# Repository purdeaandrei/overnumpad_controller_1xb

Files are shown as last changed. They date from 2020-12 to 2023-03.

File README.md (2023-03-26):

# OverNumpad Controller

This is a replacement keyboard controller, for 4th generation IBM/Lexmark
Model M keyboards, and Unicomp keyboards that use the same mounting style
over the numpad.

Licensed under CERN-OHL-P v2 or later

## Images

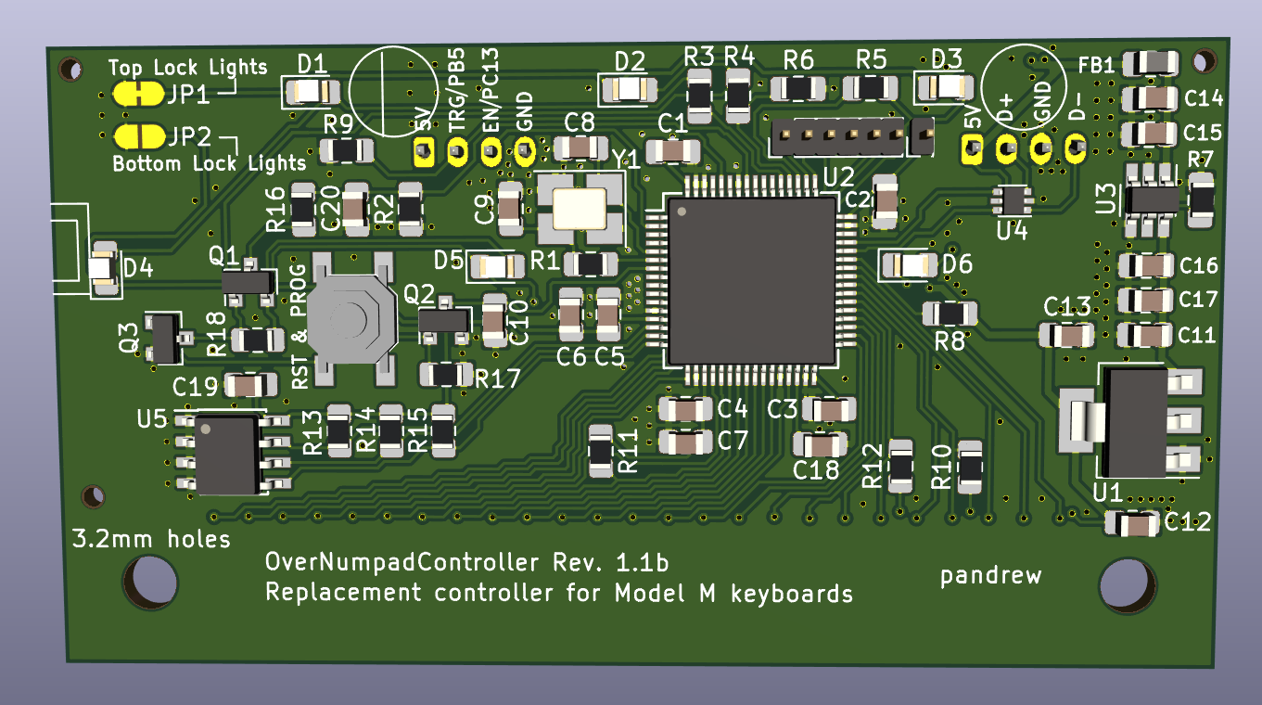
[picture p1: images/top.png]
Top of the controller board

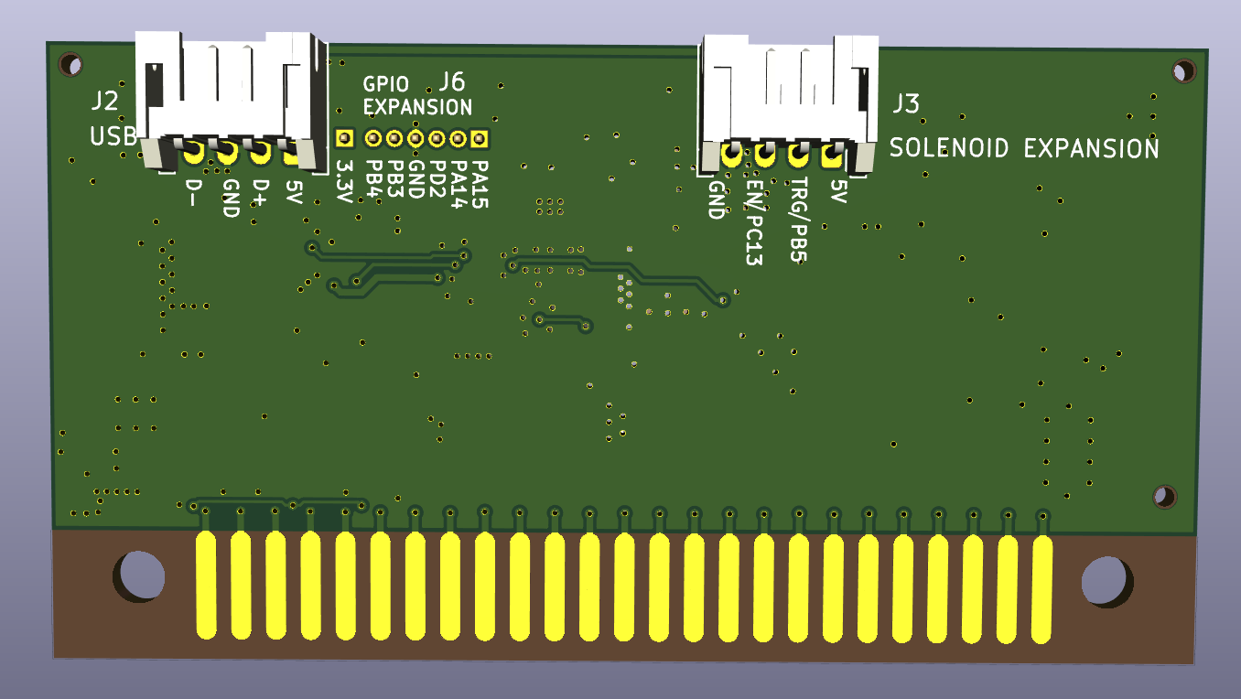
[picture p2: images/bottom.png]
Bottom of the controller board


## Keyboards supported

Only some of the listed supported keyboards has been tested at the time of release.
Some keyboards may require additional software work for support.
This list may change in the future.

* IBM/Lexmark 4th generation Model M keyboards
  See [here](https://deskthority.net/wiki/IBM_Enhanced_Keyboard) for more detail on IBM Model M keyboard generations.
  The easiest way to identify IBM/Lexmark keyboards supported by this controller is to look at the lock lights led alignment.
  Top-aligned leds means that the controller is located over the numpad, and may be replaced by this controller.
  However this controller also provides a solder jumper option, for a set of leds that are compatible with bottom-aligned
  locklight stickers.

* Various Unicomp keyboards, that use the same mounting mechanism, including:
  * Spacesaver M keyboards
  * Ultra Classic keyboards
  * Classic keyboards
  * New Model M keyboards
  * PC122 keyboards
  * The following exceptions apply:
    * The Mini M uses a bottom-mounted controller, therefore it's not supported
    * This controller may be used on keyboards that include additional input devices, such as trackballs, and pointing sticks,
      and card readers, but the controller will not support the additional devices.

## Two versions are available
The mounting holes on the controller can come in two variants:
### 3.2mm mounting holes version
* Used by IBM/Lexmark 4th generation Model M keyboards
* Used by some Unicomp keyboards, generally the older, the more likely that it uses a small-hole controller
* The small-hole variant will not fit on keyboards that use big-hole controllers
### 4.3mm mounting holes version
* Used by some Unicomp keyboards, generally the newer, the more likely that it uses a big-hole controller
* The big-hole controller will not be securely held in place, and will likely not work correctly if it is mounted on a keyboard with a small-hole controller.

## How to order from JLCPCB:
1. Go to http://jlcpcb.com , sign in to your account (create one if you don't have one)
2. Click Order Now
3. Upload the .zip file from the "order" subfolder. Make sure to select the correct version.
4. Select PCB Qty you wish to build
5. Set "Remove Order Number" to "Specify a location"
6. Scroll down, turn on the "SMT Assembly" option
7. Select "Assemble top side"
8. Select "Tooling holes" = "Added by Customer"
9. Click "I agree to the Terms and Conditions..."
10. Click "Next" on the right side
11. Click "Add BOM File", upload the "*_bom_jlc.csv" file from the "order" subfolder.
12. Click "Add CPL File", upload the "*_cpl_jlc.csv" file from the "order" subfolder.
13. Click "Next"
14. Make sure that all parts say "Confirmed" with a little check box in the final column. If it shows a greyed out "confirm", or a yellow "Inventory shortage", or there is a red "No parts selected" in the Matched Part Detail column, then some parts may be out of stock. (If parts are out of stock then your options are Wait until it's back in stock / Find equivalent replacement with correct footprint, if it is in the JLCPCB parts library / Redesign the board with a different component / Order the missing part from another supplier and solder it yourself )
15. Click "Next"
16. Double-check components look correctly rotated (this is expected to be correct unless JLCPCB makes changes to their system)
17. Double-check again, that Selected Parts has the correct number of items (21 items for v1.1b), and that Unselected Parts has 0 items.
18. Save to Cart, Check Out.

## Components of this design that have to be ordered separately:
The connectors for the USB cable, and for the solenoid driver need to be ordered separately. Compatible connectors are available from a variety of manufacturers, and distributors, one example:
* Through-hole male connector: https://www.tme.eu/en/details/ds1066-4mrw6sa/raster-signal-connectors-2-00mm/connfly/
* Female connector (for USB cable, or for ribbon cable): https://www.tme.eu/en/details/i-ds1066-scw04/raster-signal-connectors-2-00mm/connfly/
* Crimp pins for the female connector: https://www.tme.eu/en/details/t-ds1066-sc600/raster-signal-connectors-2-00mm/connfly/

## Firmware

Currently QMK firmware, and VIAL-QMK firmware are available.

For VIAL-QMK please see here:
https://github.com/purdeaandrei/vial-qmk-overnumpad-and-aristides-2862/releases/latest

For plain QMK please look for keyboards called `unicomp/*/overnumpad_1xb`, and `ibm/*/overnumpad_1xb` in upstream QMK.

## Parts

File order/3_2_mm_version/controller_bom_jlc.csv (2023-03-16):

Comment | Designator | Footprint | LCSC Part #
100nF | C1,C2,C3,C4,C10,C11,C12,C15,C16,C19 | C_0805_2012Metric_Pad1.15x1.40mm_HandSolder | C49678
10nF | C5 | C_0805_2012Metric_Pad1.15x1.40mm_HandSolder | C1710
1uF | C6,C14,C20 | C_0805_2012Metric_Pad1.15x1.40mm_HandSolder | C28323
4.7uF | C7,C18 | C_0805_2012Metric_Pad1.15x1.40mm_HandSolder | C1779
10pF | C8,C9 | C_0805_2012Metric_Pad1.15x1.40mm_HandSolder | C157608
22uF | C13,C17 | C_0805_2012Metric_Pad1.15x1.40mm_HandSolder | C45783
LED | D1,D2,D3,D4,D5,D6 | LED_0805_2012Metric_Pad1.15x1.40mm_HandSolder | C2296
Ferrite_Bead | FB1 | L_0805_2012Metric_Pad1.15x1.40mm_HandSolder | C1015
Q_PMOS_GSD AO3401A | Q1 | SOT-23 | C700954
Q_NMOS_GSD 2N7002 | Q3,Q2 | SOT-23 | C8545
390 | R1,R16 | R_0805_2012Metric_Pad1.15x1.40mm_HandSolder | C17655
62k | R2,R7,R8,R6,R9,R11,R12,R10 | R_0805_2012Metric_Pad1.15x1.40mm_HandSolder | C17783
47 | R3,R4,R5 | R_0805_2012Metric_Pad1.15x1.40mm_HandSolder | C17714
2k | R13,R14,R15,R18,R17 | R_0805_2012Metric_Pad1.15x1.40mm_HandSolder | C17604
SW_Push | SW1 | switch_K2-1187SQ-A4SW-06 | C92584
AMS1117-3.3 | U1 | SOT-223-3_TabPin2 | C6186
STM32F446RETx | U2 | LQFP-64_10x10mm_P0.5mm | C69336
TPS2553DBVR | U3 | SOT-23-6_Handsoldering | C55266
USBLC6-2SC6 | U4 | SOT-666 | C15999
24LC64 | U5 | SOIC-8_3.9x4.9mm_P1.27mm | C79988
16MHz | Y1 | Crystal_SMD_3225-4Pin_3.2x2.5mm_HandSoldering | C13738

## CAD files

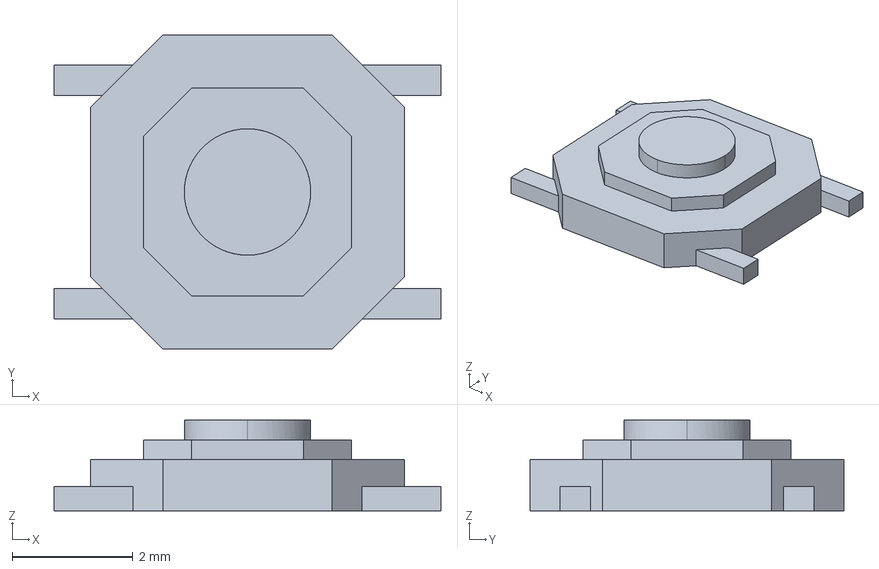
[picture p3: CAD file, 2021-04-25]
controller/push_button_3d_sources/switch2.step
6.40 x 5.20 x 1.50 mm

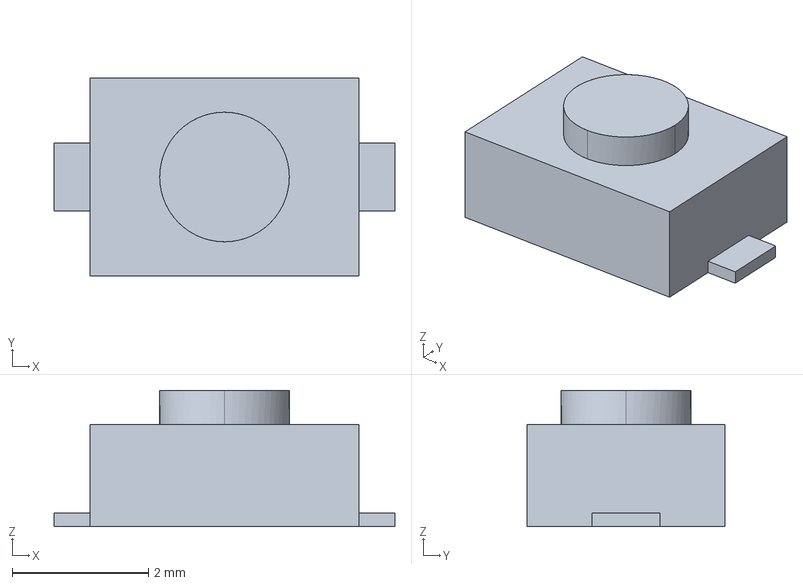
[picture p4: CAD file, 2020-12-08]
controller/push_button_3d_sources/switch.step
5.00 x 2.90 x 2.00 mm

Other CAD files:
controller/switch2_exported.step
controller/switch_exported.step
controller/push_button_3d_sources/switch.FCStd
controller/push_button_3d_sources/switch2.FCStd

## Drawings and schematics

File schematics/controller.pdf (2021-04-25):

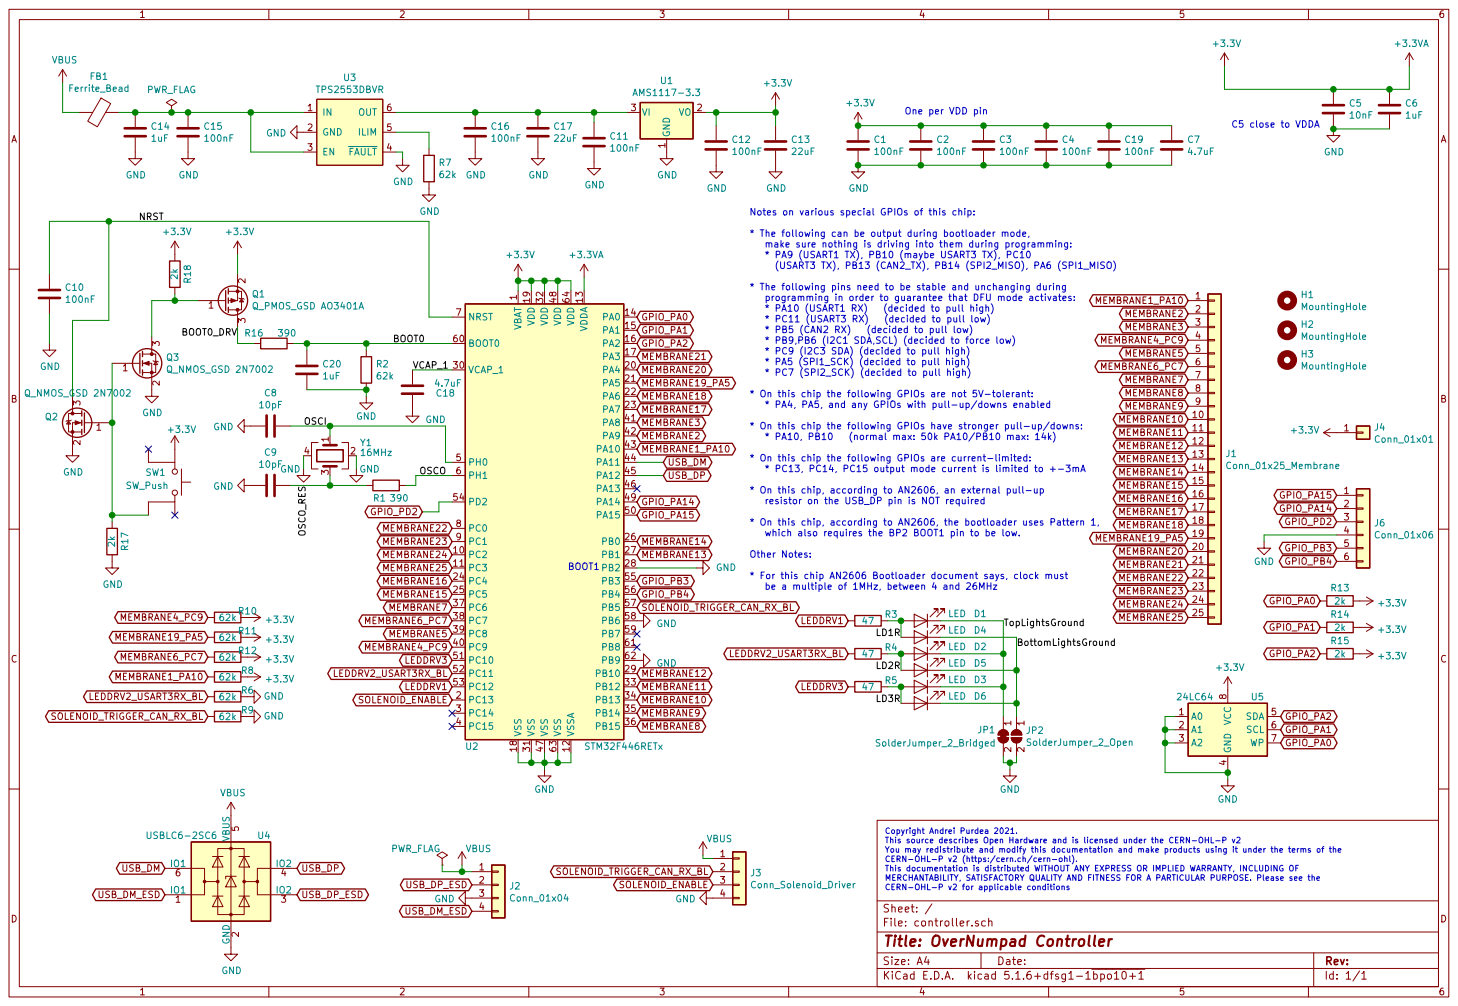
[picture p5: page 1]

* The following can be output during bootloader mode,
make sure nothing is driving into them during programming:
* PA9 (USART1 TX), PB10 (maybe USART3 TX), PC10
(USART3 TX), PB13 (CAN2_TX), PB14 (SPI2_MISO), PA6 (SPI1_MISO)

* The following pins need to be stable and unchanging during
programming in order to guarantee that DFU mode activates:
* PA10 (USART1 RX) (decided to pull high)
* PC11 (USART3 RX) (decided to pull low)
* PB5 (CAN2 RX) (decided to pull low)
* PB9,PB6 (I2C1 SDA,SCL) (decided to force low)
* PC9 (I2C3 SDA) (decided to pull high)
* PA5 (SPI1_SCK) (decided to pull high)
* PC7 (SPI2_SCK) (decided to pull high)

1 VCAP_1 30 VDD 19 VDD 32 VDD 48 VDD 64 VDDA 13 VSS 18 VSS 31 VSS 47 VSS 63 VSSA U2 12STM32F446RETx 1 2 JP2 SolderJumper_2_Open GND

* On this chip the following GPIOs are not 5V-tolerant:
* PA4, PA5, and any GPIOs with pull-up/downs enabled

* On this chip the following GPIOs have stronger pull-up/downs:
* PA10, PB10 (normal max: 50k PA10/PB10 max: 14k)

* On this chip the following GPIOs are current-limited:
* PC13, PC14, PC15 output mode current is limited to +-3mA

* On this chip, according to AN2606, an external pull-up
resistor on the USB_DP pin is NOT required

* On this chip, according to AN2606, the bootloader uses Pattern 1,
which also requires the BP2 BOOT1 pin to be low. Other Notes: * For this chip AN2606 Bootloader document says, clock must

be a multiple of 1MHz, between 4 and 26MHz

4 SDA 5 SCL 6 WP 7 VCC

Id: 1/1 Title: OverNumpad Controller File: controller.sch Sheet: /

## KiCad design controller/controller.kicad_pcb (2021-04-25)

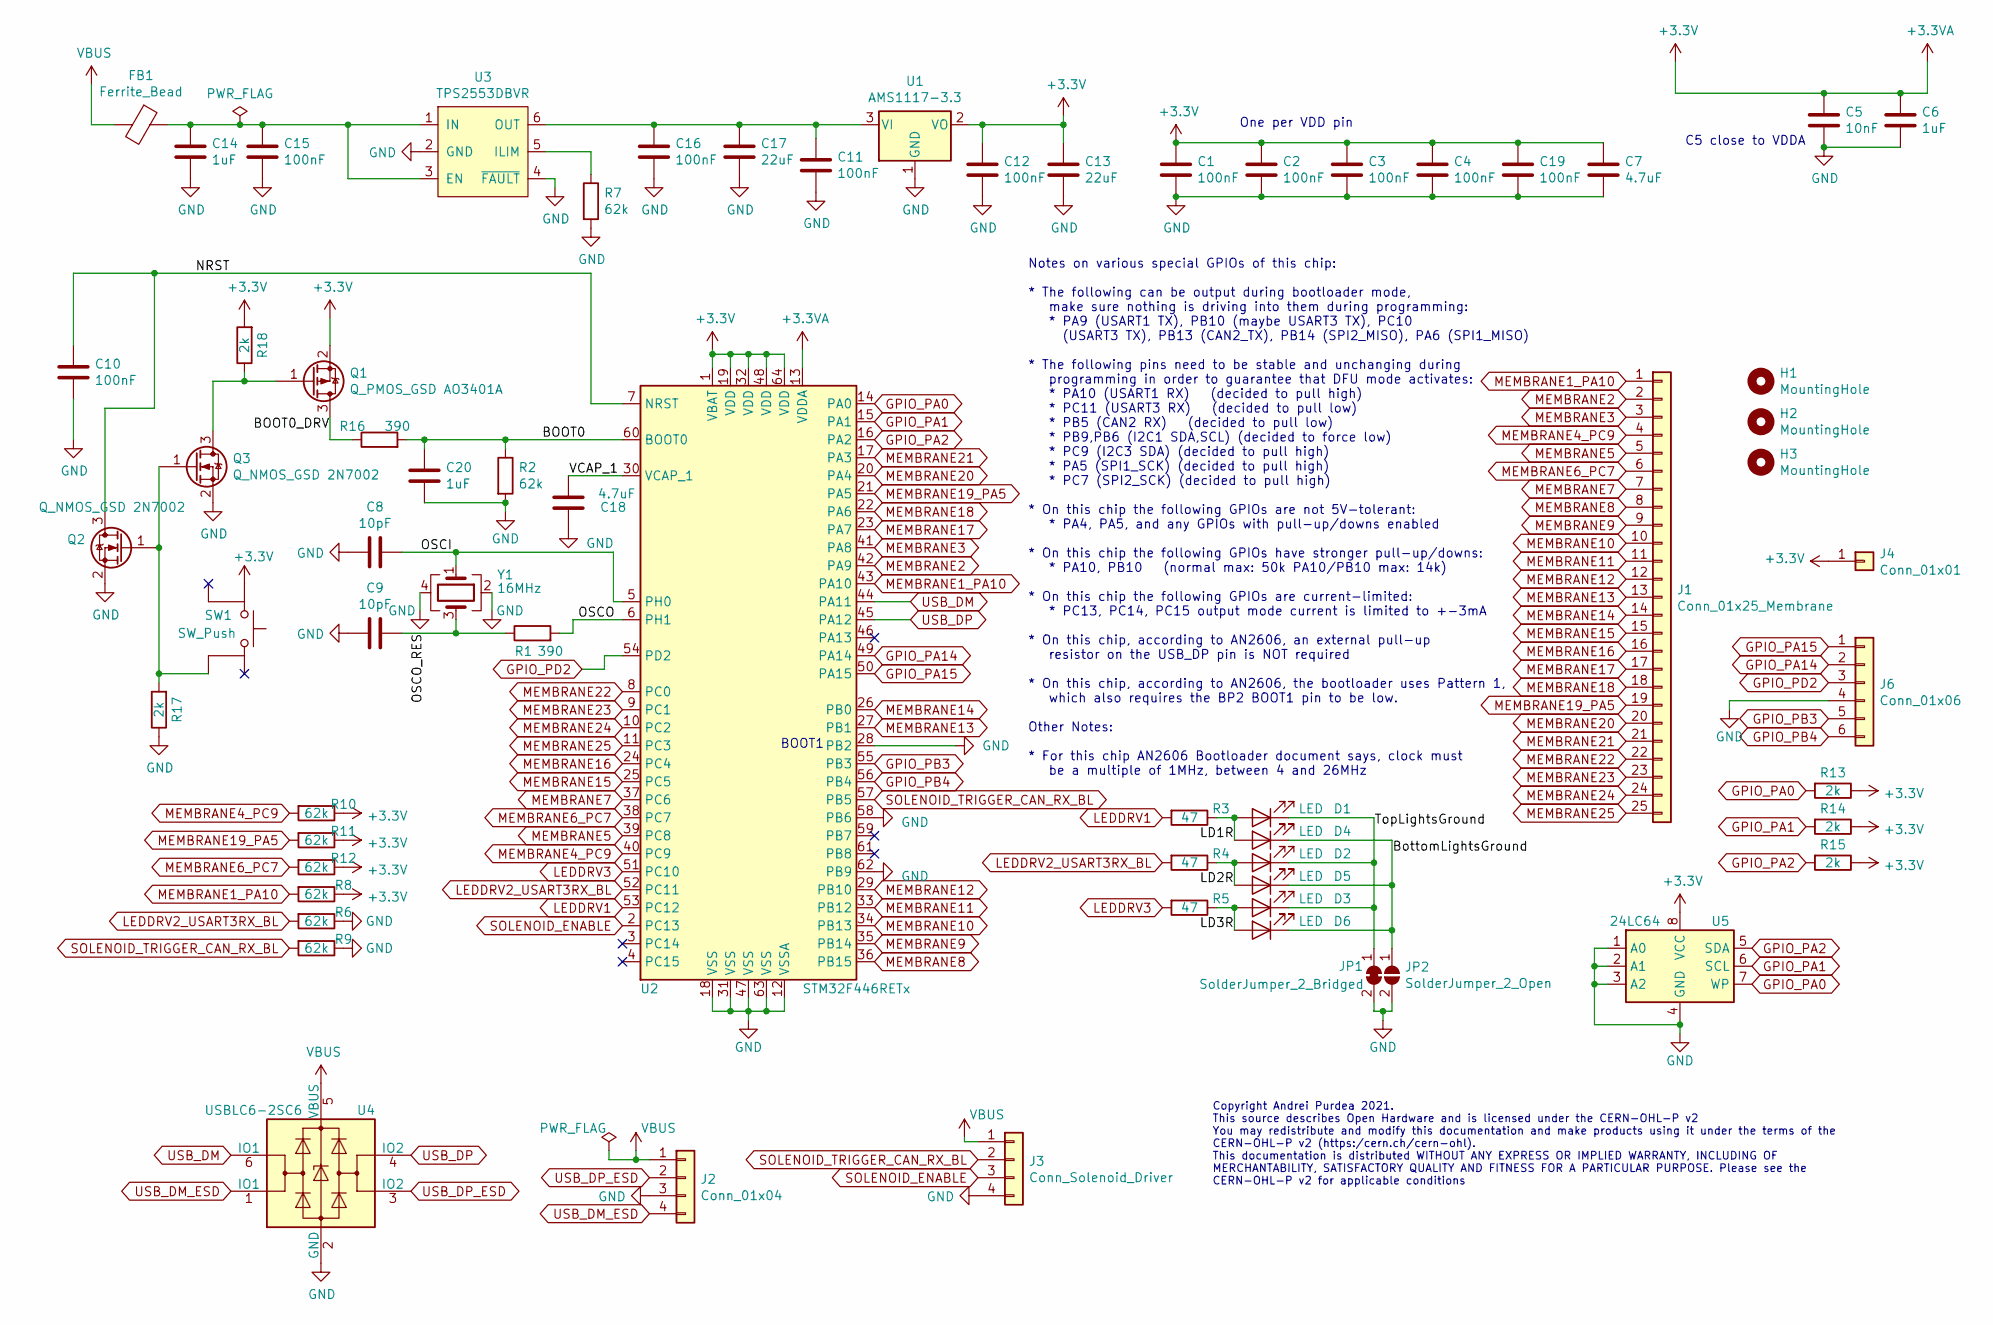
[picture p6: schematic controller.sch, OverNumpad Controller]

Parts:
C1, C2, C3, C4, C10, C11, C12, C15, C16, C19: 100nF; C_0805_2012Metric_Pad1.15x1.40mm_HandSolder; LCSC C49678
C5: 10nF; C_0805_2012Metric_Pad1.15x1.40mm_HandSolder; LCSC C1710
C6, C14, C20: 1uF; C_0805_2012Metric_Pad1.15x1.40mm_HandSolder; LCSC C28323
C7, C18: 4.7uF; C_0805_2012Metric_Pad1.15x1.40mm_HandSolder; LCSC C1779
C8, C9: 10pF; C_0805_2012Metric_Pad1.15x1.40mm_HandSolder; LCSC C1785
C13, C17: 22uF; C_0805_2012Metric_Pad1.15x1.40mm_HandSolder; LCSC C45783
D1, D2, D3, D4, D5, D6: LED; LED_0805_2012Metric_Pad1.15x1.40mm_HandSolder; LCSC C2296
FB1: Ferrite_Bead; L_0805_2012Metric_Pad1.15x1.40mm_HandSolder; LCSC C1015
H1, H2, H3: MountingHole; tooling_hole
J1: Conn_01x25_Membrane; membrane_connector
J2: Conn_01x04; JST_PH_S4B-PH-K_1x04_P2.00mm_Horizontal
J3: Conn_Solenoid_Driver; JST_PH_S4B-PH-K_1x04_P2.00mm_Horizontal
J4: Conn_01x01; PinHeader_1x01_P1.27mm_Vertical_mod_no_courtyard_no_ref
J6: Conn_01x06; PinHeader_1x06_P1.27mm_Vertical
JP1: SolderJumper_2_Bridged; shortable_shorted
JP2: SolderJumper_2_Open; shortable
Q1: Q_PMOS_GSD AO3401A; SOT-23; LCSC C15127
Q2, Q3: Q_NMOS_GSD 2N7002; SOT-23; LCSC C8545
R1, R16: 390; R_0805_2012Metric_Pad1.15x1.40mm_HandSolder; LCSC C17655
R2, R6, R7, R8, R9, R10, R11, R12: 62k; R_0805_2012Metric_Pad1.15x1.40mm_HandSolder; LCSC C17783
R3, R4, R5: 47; R_0805_2012Metric_Pad1.15x1.40mm_HandSolder; LCSC C17714
R13, R14, R15, R17, R18: 2k; R_0805_2012Metric_Pad1.15x1.40mm_HandSolder; LCSC C17604
SW1: SW_Push; switch_K2-1187SQ-A4SW-06; LCSC C92584
U1: AMS1117-3.3; SOT-223-3_TabPin2; LCSC C6186
U2: STM32F446RETx; LQFP-64_10x10mm_P0.5mm; LCSC C69336
U3: TPS2553DBVR; SOT-23-6_Handsoldering; LCSC C55266
U4: USBLC6-2SC6; SOT-666; LCSC C15999
U5: 24LC64; SOIC-8_3.9x4.9mm_P1.27mm; LCSC C79988
Y1: 16MHz; Crystal_SMD_3225-4Pin_3.2x2.5mm_HandSoldering; LCSC C13738

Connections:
+3.3VA: C1.1, C2.1, C3.1, C4.1, C5.1, C6.1, C7.1, C12.1, C13.1, C19.1, J4.1, Q1.2 (S), R8.1, R10.1, R11.1, R12.1, R13.1, R14.1, R15.1, R18.2, SW1.1, U1.2 (VO), U2.1 (VBAT), U2.13 (VDDA), U2.19 (VDD), U2.32 (VDD), U2.48 (VDD), U2.64 (VDD), U5.8 (VCC)
/BOOT0: C20.1, R2.1, R16.2, U2.60 (BOOT0)
/BOOT0_DRV: Q1.3 (D), R16.1
/BottomLightsGround: D4.1 (K), D5.1 (K), D6.1 (K), JP2.1 (A)
/LD1R: D1.2 (A), D4.2 (A), R3.1
/LD2R: D2.2 (A), D5.2 (A), R4.1
/LD3R: D3.2 (A), D6.2 (A), R5.1
/NRST: C10.2, Q2.3 (D), U2.7 (NRST)
/OSCI: C8.1, U2.5 (PH0), Y1.1
/OSCO: R1.2, U2.6 (PH1)
/OSCO_RES: C9.1, R1.1, Y1.3
/TopLightsGround: D1.1 (K), D2.1 (K), D3.1 (K), JP1.1 (A)
/VCAP_1: C18.1, U2.30 (VCAP_1)
GND: C1.2, C2.2, C3.2, C4.2, C5.2, C6.2, C7.2, C8.2, C9.2, C10.1, C11.2, C12.2, C13.2, C14.2, C15.2, C16.2, C17.2, C18.2, C19.2, C20.2, J2.3, J3.4, J6.4, JP1.2 (B), JP2.2 (B), Q2.2 (S), Q3.2 (S), R2.2, R6.1, R7.2, R9.1, R17.1, U1.1 (GND), U2.12 (VSSA), U2.18 (VSS), U2.28 (PB2), U2.31 (VSS), U2.47 (VSS), U2.58 (PB6), U2.62 (PB9), U2.63 (VSS), U3.2 (GND), U3.4 (~FAULT), U4.2 (GND), U5.1 (A0), U5.2 (A1), U5.3 (A2), U5.4 (GND), Y1.2, Y1.4
GPIO_PA0: R13.2, U2.14 (PA0), U5.7 (WP)
GPIO_PA1: R14.2, U2.15 (PA1), U5.6 (SCL)
GPIO_PA2: R15.2, U2.16 (PA2), U5.5 (SDA)
GPIO_PA14: J6.2, U2.49 (PA14)
GPIO_PA15: J6.1, U2.50 (PA15)
GPIO_PB3: J6.5, U2.55 (PB3)
GPIO_PB4: J6.6, U2.56 (PB4)
GPIO_PD2: J6.3, U2.54 (PD2)
LEDDRV1: R3.2, U2.53 (PC12)
LEDDRV2_USART3RX_BL: R4.2, R6.2, U2.52 (PC11)
LEDDRV3: R5.2, U2.51 (PC10)
MEMBRANE1_PA10: J1.1, R8.2, U2.43 (PA10)
MEMBRANE2: J1.2, U2.42 (PA9)
MEMBRANE3: J1.3, U2.41 (PA8)
MEMBRANE4_PC9: J1.4, R10.2, U2.40 (PC9)
MEMBRANE5: J1.5, U2.39 (PC8)
MEMBRANE6_PC7: J1.6, R12.2, U2.38 (PC7)
MEMBRANE7: J1.7, U2.37 (PC6)
MEMBRANE8: J1.8, U2.36 (PB15)
MEMBRANE9: J1.9, U2.35 (PB14)
MEMBRANE10: J1.10, U2.34 (PB13)
MEMBRANE11: J1.11, U2.33 (PB12)
MEMBRANE12: J1.12, U2.29 (PB10)
MEMBRANE13: J1.13, U2.27 (PB1)
MEMBRANE14: J1.14, U2.26 (PB0)
MEMBRANE15: J1.15, U2.25 (PC5)
MEMBRANE16: J1.16, U2.24 (PC4)
MEMBRANE17: J1.17, U2.23 (PA7)
MEMBRANE18: J1.18, U2.22 (PA6)
MEMBRANE19_PA5: J1.19, R11.2, U2.21 (PA5)
MEMBRANE20: J1.20, U2.20 (PA4)
MEMBRANE21: J1.21, U2.17 (PA3)
MEMBRANE22: J1.22, U2.8 (PC0)
MEMBRANE23: J1.23, U2.9 (PC1)
MEMBRANE24: J1.24, U2.10 (PC2)
MEMBRANE25: J1.25, U2.11 (PC3)
unnamed: C11.1, C16.1, C17.1, U1.3 (VI), U3.6 (OUT)
unnamed: C14.1, C15.1, FB1.1, U3.1 (IN), U3.3 (EN)
unnamed: Q1.1 (G), Q3.3 (D), R18.1
unnamed: Q2.1 (G), Q3.1 (G), R17.2, SW1.4
unnamed: R7.1, U3.5 (ILIM)
SOLENOID_ENABLE: J3.3, U2.2 (PC13)
SOLENOID_TRIGGER_CAN_RX_BL: J3.2, R9.2, U2.57 (PB5)
USB_DM: U2.44 (PA11), U4.6 (IO1)
USB_DM_ESD: J2.4, U4.1 (IO1)
USB_DP: U2.45 (PA12), U4.4 (IO2)
USB_DP_ESD: J2.2, U4.3 (IO2)
VBUS: FB1.2, J2.1, J3.1, U4.5 (VBUS)

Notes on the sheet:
One per VDD pin
C5 close to VDDA
Notes on various special GPIOs of this chip: * The following can be output during bootloader mode, make sure nothing is driving into them during programming: * PA9 (USART1 TX), PB10 (maybe USART3 TX), PC10 (USART3 TX), PB13 (CAN2_TX), PB14 (SPI2_MISO), PA6 (SPI1_MISO) * The following pins need to b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
BOOT1
Copyright Andrei Purdea 2021. This source describes Open Hardware and is licensed under the CERN-OHL-P v2 You may redistribute and modify this documentation and make products using it under the terms of the CERN-OHL-P v2 (https:/cern.ch/cern-ohl). This documentation is distributed WITHOUT ANY EXPRE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

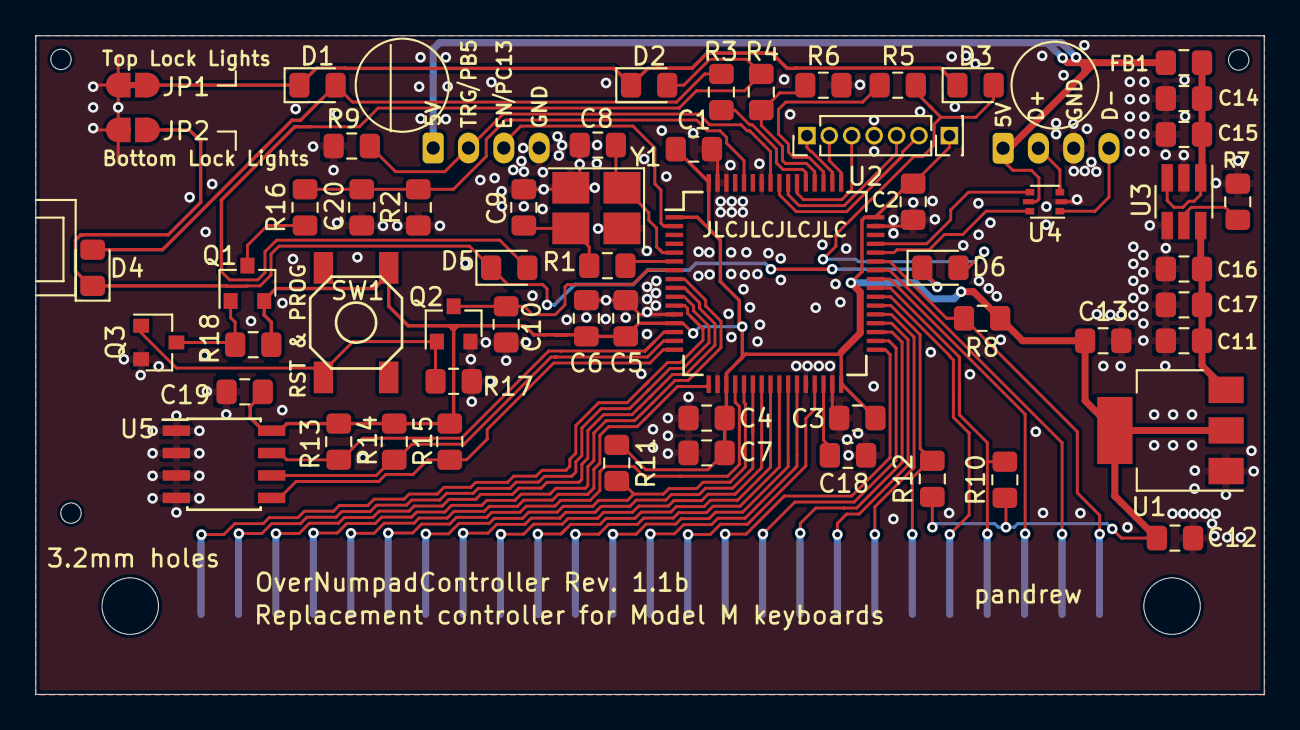
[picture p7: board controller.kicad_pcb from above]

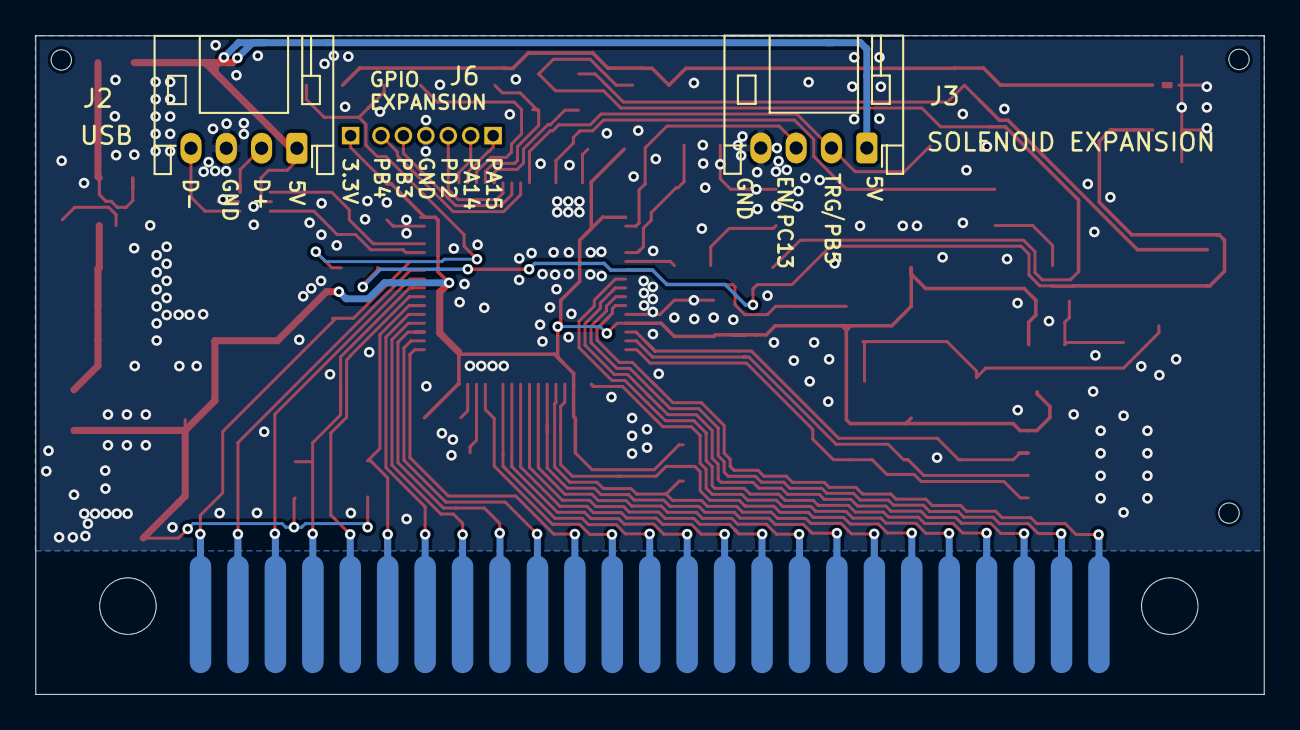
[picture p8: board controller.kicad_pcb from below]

Board: 2 copper layers, 69.6 x 37.3 mm, 65 parts (3 on the bottom side), 62 nets.

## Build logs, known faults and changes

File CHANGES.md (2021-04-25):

Differences between overnumpad controller Rev. 1.1b, and 1.0b with patchboard.
 - Lock light jumpers:
   - On Rev. 1.1b JP1 is shorted by default. No action is necessary if the user just wants to use the top-aligned locklights.
   - On Rev. 1.1b if the user wants to use bottom-aligned lock-lights, they must cut the JP1 short in the middle with a sharp
     knife, and must short JP2 by placing a solder blob on it.
   - On Rev. 1.0b neither JP1 or JP2 are shorted by default, the user must place a solder blob on the pads enabling the desired
     locklights.
 - The position of some components is slightly different.
 - On Rev. 1.1b an extra 3.3v pin is available on the J6 GPIO expansion.
 - A patchboard-less Rev. 1.0b should never exist in the wild.

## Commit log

2020-12-08 added solenoid driver
    [controller.kicad_pcb, controller.sch]
2020-12-10 added gpio header and other updates
    [controller.kicad_pcb, controller.sch]
2020-12-10 LED current limit resistors changed to 47 ohm
    [controller.kicad_pcb, controller.sch]
2020-12-10 more updates
    [controller.kicad_pcb, controller.sch]
2021-01-24 Fixed switches -- they are SMD
    [controller.kicad_pcb]
2021-03-22 Overnumpad Controller v1.0
    [controller.kicad_pcb]
2021-03-22 Added version 1.0b, and exported 3mm version gerber
    [controller.kicad_pcb, controller.sch, controller_bom_jlc.csv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]
2021-03-22 Added 4.1mm hole variant gerbers
    [controller_bom_jlc.csv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]
2021-04-10 manually fixed rotations
    [controller_cpl_jlc.csv]
2021-04-25 Added v1.1b version
    [controller.kicad_pcb, controller.sch, controller_bom_jlc.csv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]
2021-04-25 Prepare the design for release
    [controller.kicad_pcb, controller.sch, switch.FCStd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]
2021-04-25 Replacing LCSC reference for P-channel mosfet, to same transistor from different manufacturer.
    [controller.sch, controller_bom_jlc.csv]
2023-03-16 Replaced out-of-stock part
    [controller.sch, controller_bom_jlc.csv]
2023-03-16 fixed rotation of U2
    [controller_cpl_jlc.csv]
